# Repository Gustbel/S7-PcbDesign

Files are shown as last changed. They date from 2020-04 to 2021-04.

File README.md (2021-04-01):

# Diseño en ALTIUM del PCB del Summits 7 - Versión RTM 1.0

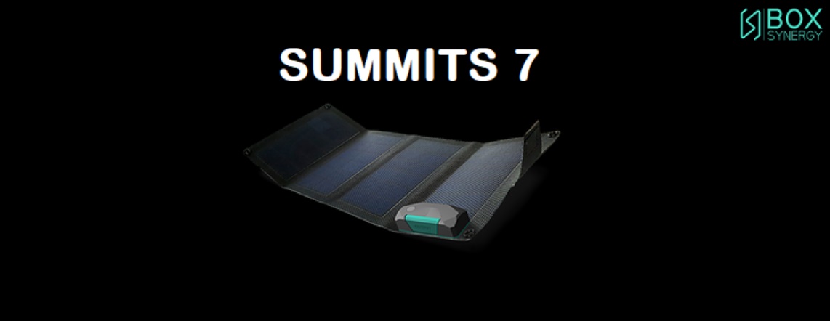
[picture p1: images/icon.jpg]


## PCB Summits 7 - Versión RTM 1.0

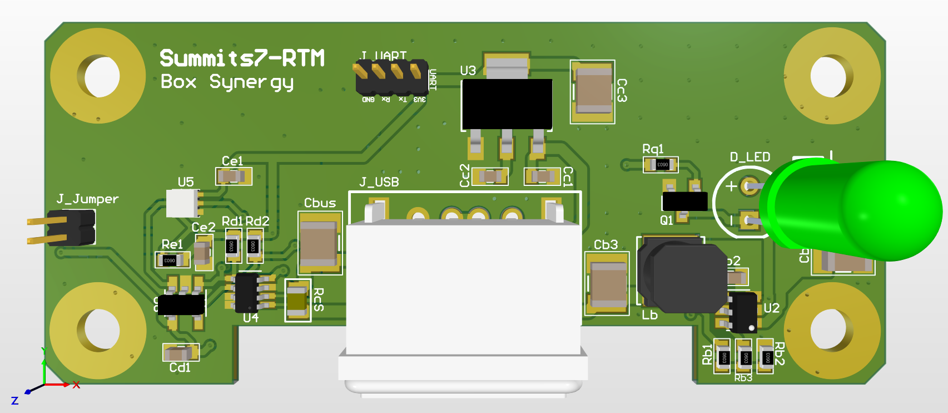
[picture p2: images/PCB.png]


## ¿Para que es este repositorio? 

 - Este repositorio servirá para tener un **Control de Versiones**, **Acceso Remoto al developer** y **Permitir Acceso continuo de avances** al equipo de trabajo de *Box Synergy*.

## ¿Como funciona este repositorio?

Este repositorio tiene dos Branches (o Ramas):

* **master:** Contiene la última versión estable, es decir después de cumplir un objetivo en el diseño y se compruebe que fue estable, se hace un salvado de datos en esta rama. Para consultar avances es preferible mirar esta rama ya que es la más estable.
* **develop:** Contiene la versión que está en desarrollo, por lo tanto probablemente inestable y con errores naturales durante el proceso de desarrollo. Esta rama es la utilizada por el desarrollador y por algún colaborador que quiera mirar o ayudar en pleno desarrollo.

## ¿Como puedo consultar el proyecto?
1. Si no lo tiene, instalar cualquier versión de Altium Designer en su PC.
2. Posicionese en el **BRANCH** (o rama) que usted desee descargar. Para seleccionar el branch haga click en el menú desplegable que está debajo del título del Repositorio (mas específicamente debajo de la descripción del repositorio) y elija el Branch que usted desee.
3. Descargar este repositorio desde un botón con tres puntos **(...)** que se encuentra en la esquina superior derecha del repositorio (al lado del botón *Clone*), luego seleccione ***Download Repository***. Se descargará un archivo comprimido *.zip*.
4. Descomprima la carpeta del Repositorio en alguna carpeta conocida.
5. Abra Altium y seleccione el proyecto que acaba de descomprimir.

## Consultas
- electronic@box-synergy.com	---  Contacto Área Electrónica de Box Synergy
- gustavobelbruno@gmail.com		---  Contacto Gustavo Belbruno - Summits 7 Beta Project Main Designer

																Repository created 05/04/2020

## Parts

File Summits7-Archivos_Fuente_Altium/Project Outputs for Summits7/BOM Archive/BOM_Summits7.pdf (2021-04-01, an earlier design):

## BOM_Summits7_RTM

Component List / BOM Archive | Company: | Box Synergy

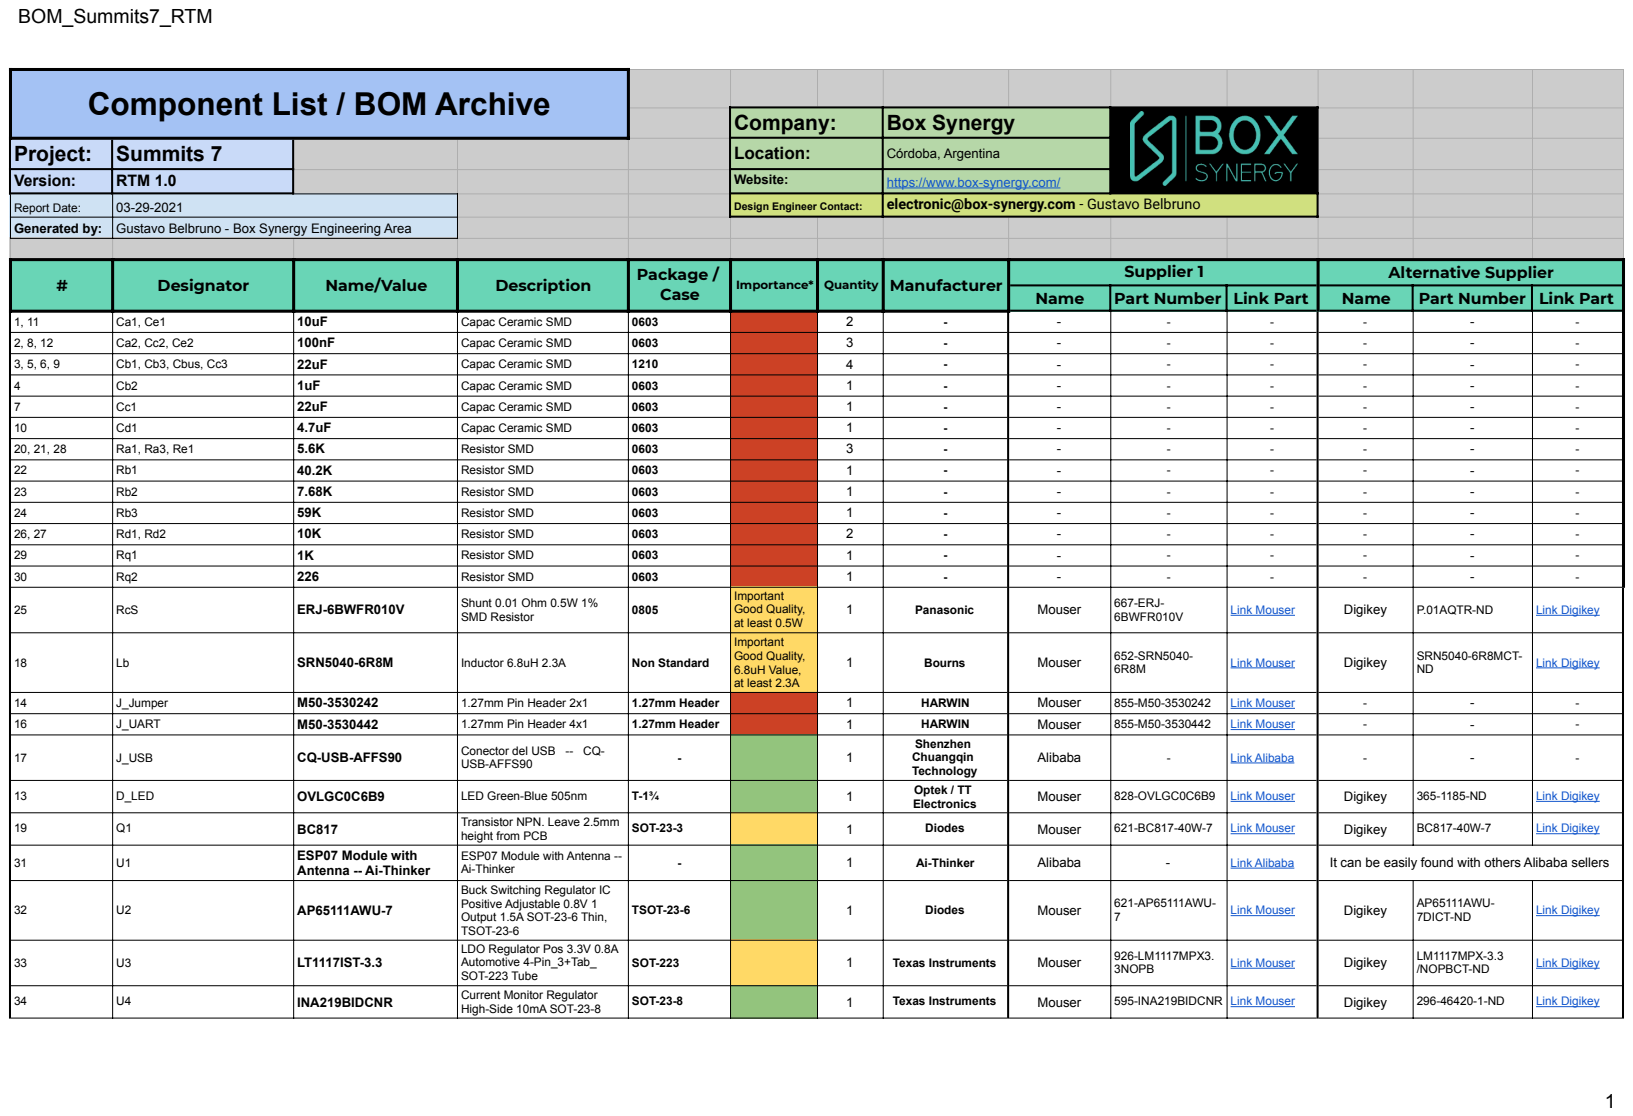
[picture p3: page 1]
Report Date:; Design Engineer Contact:; electronic@box-synergy.com - Gustavo Belbruno; Generated by:; Gustavo Belbruno - Box Synergy Engineering Area

Project: | Summits 7 | Location: | Córdoba, Argentina

Version: | RTM 1.0 | Website: | https://www.box-synergy.com/

# | Designator | Name/Value | Description | Package / Case | Importance* | Quantity | Manufacturer | Supplier 1 | Alternative Supplier

Name | Part Number | Link Part | Name | Part Number | Link Part

1, 11 | Ca1, Ce1 | 10uF | Capac Ceramic SMD | 0603 | | 2 | - | - | - | - | - | - | -

2, 8, 12 | Ca2, Cc2, Ce2 | 100nF | Capac Ceramic SMD | 0603 | | 3 | - | - | - | - | - | - | -

3, 5, 6, 9 | Cb1, Cb3, Cbus, Cc3 | 22uF | Capac Ceramic SMD | 1210 | | 4 | - | - | - | - | - | - | -

4 | Cb2 | 1uF | Capac Ceramic SMD | 0603 | | 1 | - | - | - | - | - | - | -

7 | Cc1 | 22uF | Capac Ceramic SMD | 0603 | | 1 | - | - | - | - | - | - | -

10 | Cd1 | 4.7uF | Capac Ceramic SMD | 0603 | | 1 | - | - | - | - | - | - | -

20, 21, 28 | Ra1, Ra3, Re1 | 5.6K | Resistor SMD | 0603 | | 3 | - | - | - | - | - | - | -

22 | Rb1 | 40.2K | Resistor SMD | 0603 | | 1 | - | - | - | - | - | - | -

23 | Rb2 | 7.68K | Resistor SMD | 0603 | | 1 | - | - | - | - | - | - | -

24 | Rb3 | 59K | Resistor SMD | 0603 | | 1 | - | - | - | - | - | - | -

26, 27 | Rd1, Rd2 | 10K | Resistor SMD | 0603 | | 2 | - | - | - | - | - | - | -

29 | Rq1 | 1K | Resistor SMD | 0603 | | 1 | - | - | - | - | - | - | -

30 | Rq2 | 226 | Resistor SMD | 0603 | | 1 | - | - | - | - | - | - | -
25 | RcS | ERJ-6BWFR010V | Shunt 0.01 Ohm 0.5W 1% SMD Resistor | 0805 | Important Good Quality, at least 0.5W | 1 | Panasonic | Mouser | 667-ERJ-6BWFR010V | Link Mouser (https://www.mouser.com/ProductDetail/Panasonic/ERJ-6BWFR010V) | Digikey | P.01AQTR-ND | Link Digikey (https://www.digikey.com/product-detail/en/panasonic-electronic-components/ERJ-6BWFR010V/P-01AQTR-ND/1466354)

18 | Lb | SRN5040-6R8M | Inductor 6.8uH 2.3A | Non Standard | Important Good Quality, 6.8uH Value, at least 2.3A | 1 | Bourns | Mouser | 652-SRN5040-6R8M | Link Mouser (https://www.mouser.com/ProductDetail/Bourns/SRN5040-6R8M) | Digikey | SRN5040-6R8MCT-ND | Link Digikey (https://www.digikey.co.uk/product-detail/en/bourns-inc/SRN5040-6R8M/SRN5040-6R8MCT-ND/4867788)

14 | J_Jumper | M50-3530242 | 1.27mm Pin Header 2x1 | 1.27mm Header | | 1 | HARWIN | Mouser | 855-M50-3530242 | Link Mouser (https://www.mouser.com/ProductDetail/Harwin/M50-3530242?qs=%252BdQmOuGyFcFfqfwYQe%2FxZw%3D%3D) | - | - | -

16 | J_UART | M50-3530442 | 1.27mm Pin Header 4x1 | 1.27mm Header | | 1 | HARWIN | Mouser | 855-M50-3530442 | Link Mouser (https://www.mouser.com/ProductDetail/Harwin/M50-3530242?qs=%252BdQmOuGyFcFfqfwYQe%2FxZw%3D%3D) | - | - | -
17 | J_USB | CQ-USB-AFFS90 | Conector del USB -- CQ-USB-AFFS90 | - | | 1 | Shenzhen Chuangqin Technology | Alibaba | - | Link Alibaba (https://www.alibaba.com/product-detail/4-Pin-Waterproof-IPX8-USB-A_62420880597.html) | - | - | -

13 | D_LED | OVLGC0C6B9 | LED Green-Blue 505nm | T-1¾ | | 1 | Optek / TT Electronics | Mouser | 828-OVLGC0C6B9 | Link Mouser (https://www.mouser.com/ProductDetail/Optek-TT-Electronics/OVLGC0C6B9?qs=3Y%252Bkm9Tbno7Cu33sFcjmUA%3D%3D) | Digikey | 365-1185-ND | Link Digikey (https://www.digikey.co.uk/product-detail/en/tt-electronics-optek-technology/OVLGC0C6B9/365-1185-ND/827121)

19 | Q1 | BC817 | Transistor NPN. Leave 2.5mm height from PCB | SOT-23-3 | | 1 | Diodes | Mouser | 621-BC817-40W-7 | Link Mouser (https://www.mouser.com/ProductDetail/Diodes-Incorporated/BC817-40W-7/) | Digikey | BC817-40W-7 | Link Digikey (https://www.digikey.com/en/products/detail/BC817-40W-7/BC817-40WDICT-ND/816560)

31 | U1 | ESP07 Module with Antenna -- Ai-Thinker | ESP07 Module with Antenna --Ai-Thinker | - | | 1 | Ai-Thinker | Alibaba | - | Link Alibaba (https://www.alibaba.com/product-detail/Ai-Thinker-ESP-07-ESP8266-Wifi_62009924257.html) | It can be easily found with others Alibaba sellers

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

## BOM_Summits7_RTM

2

35 | U5 | VEML6030 | Optical Ambiental Light Sensor I2C with Interrupt | Surface-mount (not detailed in datasheet) | 1 | Vishay | Mouser | 78-VEML6030 | Link Mouser (https://www.mouser.com/ProductDetail/Vishay-Semiconductors/VEML6030/?qs=oeTp6q%252Bm7GMZCCnCKRrv4g%3D%3D) | - | - | -
36 | U6 | 24CW1280T-I/OT | EEPROM 128K I2C | SOT-23-5 | 1 | Microchip | Mouser | 579-24CW1280T-I/OT | Link Mouser (https://www.mouser.com/ProductDetail/Microchip-Technology/24CW1280T-I-OT?qs=qSfuJ%252Bfl%2Fd6lIWZGGRvkYA==) | Digikey | 24CW1280T-I/OTCT-ND | Link Digikey (https://www.digikey.com/product-detail/en/microchip-technology/24CW1280T-I-OT/24CW1280T-I-OTCT-ND/9607061)
15 | J_Solar | Connx2_Panel | No component
*Importance: Refers to the importance of using the designated component and not a default replacement | This is a critical device and was specially calculated, it should not be exchanged for any device. In case of not obtaining this device, please contact the design engineer.
| If possible, use the supplied device. In case there is difficulty in obtaining it, you can use another one with similar characteristics, but as long as the device has a complete datasheet where its parameters can be consulted.
| This is a regular device and you can choose the device that suits you.

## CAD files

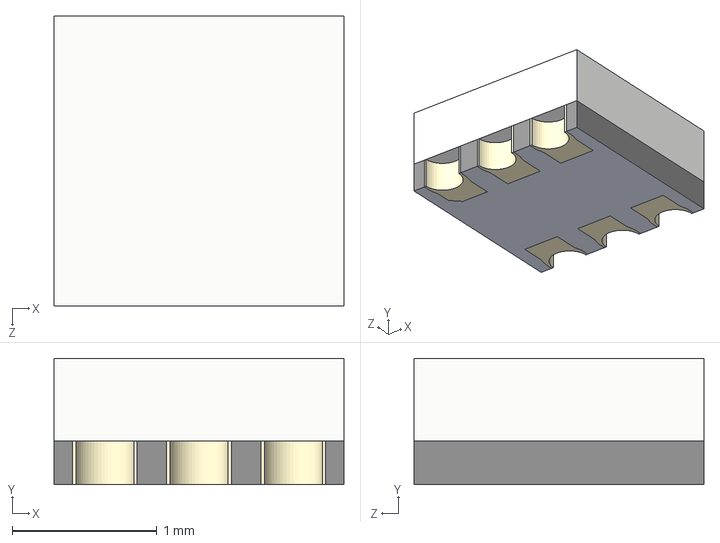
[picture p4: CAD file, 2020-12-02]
Summits7-Archivos_Fuente_Altium/LibraryUsed/Originales/STEP_Models/DFN-6-1_2.step
2.00 x 0.87 x 2.00 mm

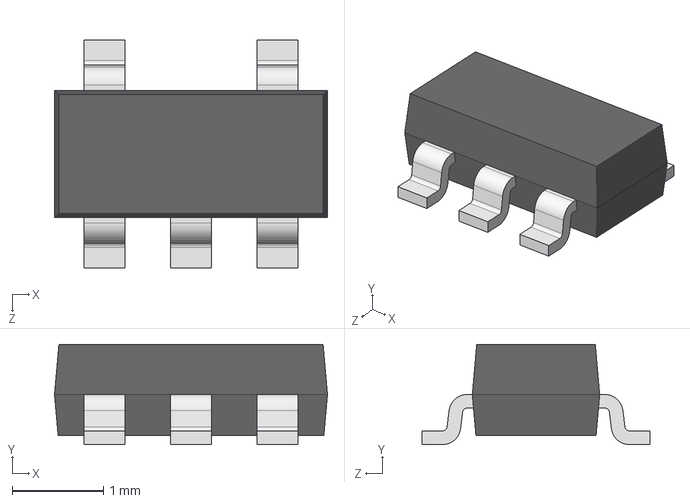
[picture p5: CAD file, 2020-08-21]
Summits7-Archivos_Fuente_Altium/LibraryUsed/Originales/STEP_Models/SOT-23-5-EEPROM.step
3.00 x 1.10 x 2.50 mm

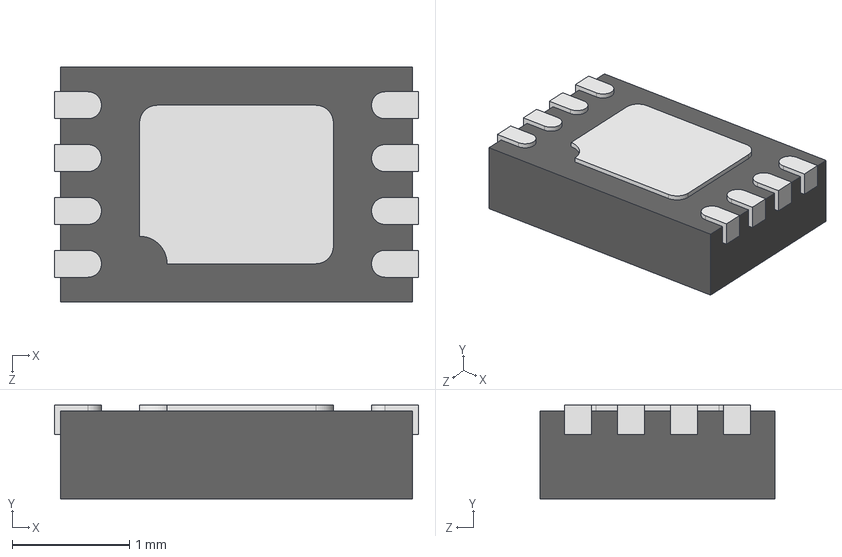
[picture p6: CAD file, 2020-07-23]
Summits7-Archivos_Fuente_Altium/LibraryUsed/Originales/STEP_Models/DFN8.step
3.10 x 0.8 x 2.00 mm

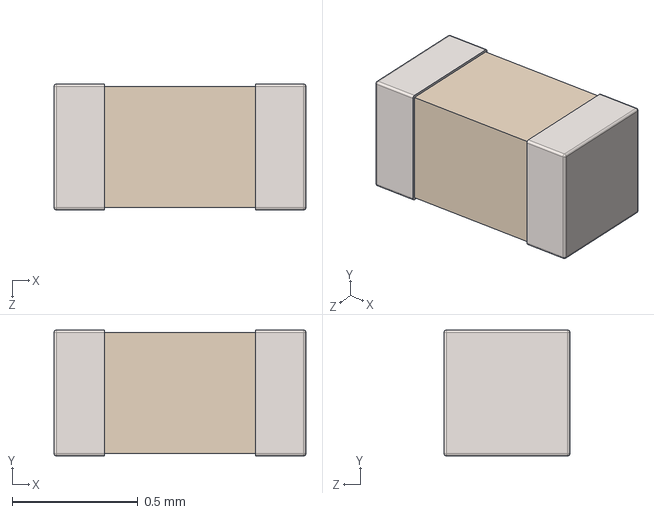
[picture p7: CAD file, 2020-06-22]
Summits7-Archivos_Fuente_Altium/LibraryUsed/Originales/STEP_Models/Cap0402.step
1.00 x 0.5 x 0.5 mm

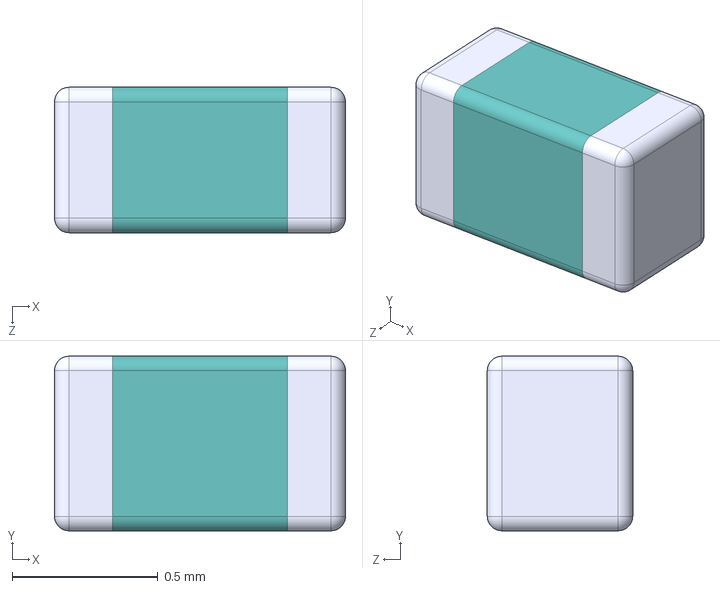
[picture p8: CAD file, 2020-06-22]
Summits7-Archivos_Fuente_Altium/LibraryUsed/Originales/STEP_Models/Ind0402.step
1.00 x 0.6 x 0.5 mm

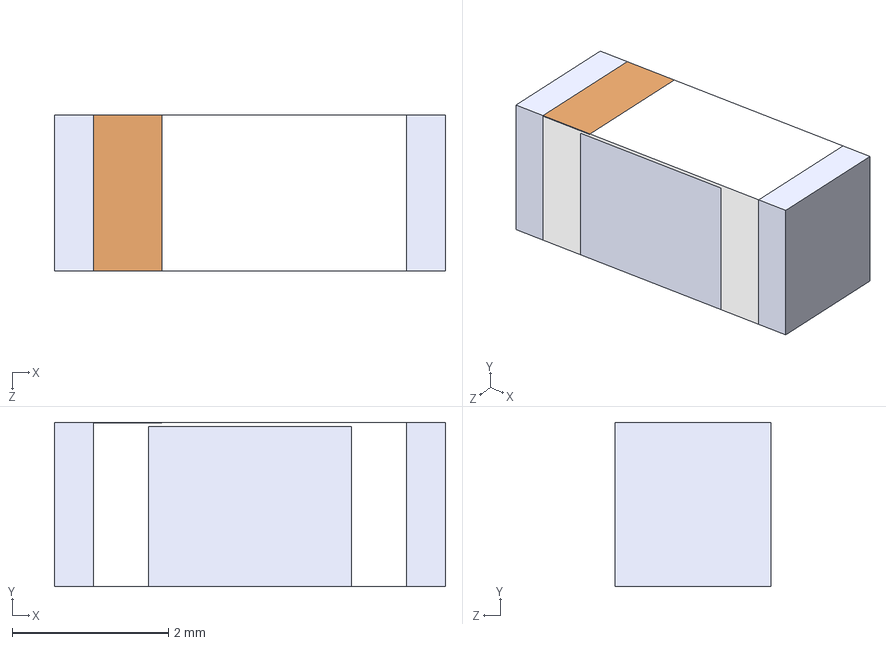
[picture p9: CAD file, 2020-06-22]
Summits7-Archivos_Fuente_Altium/LibraryUsed/Originales/STEP_Models/AntennaCeramic--2450AT42B100E.STEP
5.00 x 2.10 x 2.00 mm

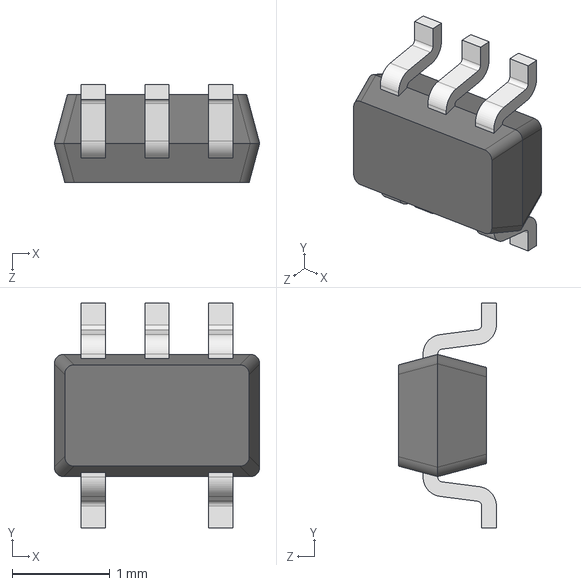
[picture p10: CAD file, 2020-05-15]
Summits7-Archivos_Fuente_Altium/LibraryUsed/Originales/STEP_Models/OPAMP-SC70-5.step
2.10 x 2.30 x 1.00 mm

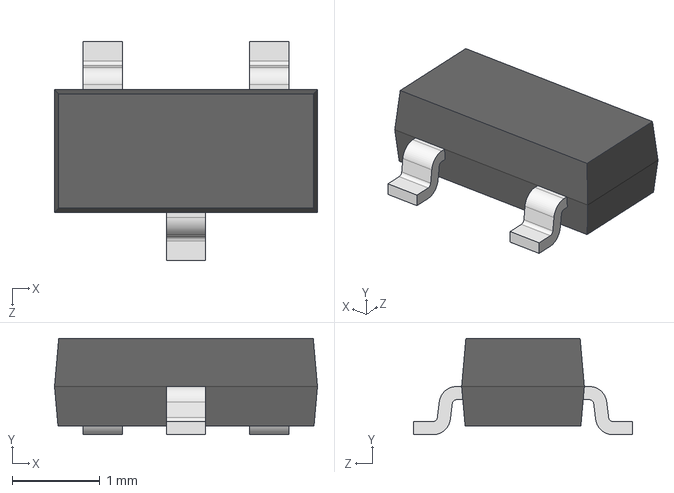
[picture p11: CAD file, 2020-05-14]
Summits7-Archivos_Fuente_Altium/LibraryUsed/Originales/STEP_Models/SOT-23_TransistorNPN.step
3.00 x 1.10 x 2.50 mm

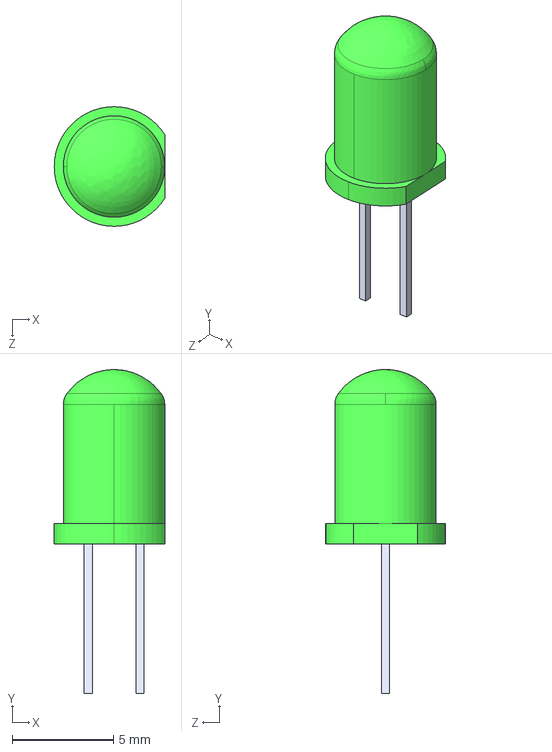
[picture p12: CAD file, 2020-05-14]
Summits7-Archivos_Fuente_Altium/LibraryUsed/Originales/STEP_Models/LED-GREEN-5mm.step
5.45 x 16.0 x 5.90 mm

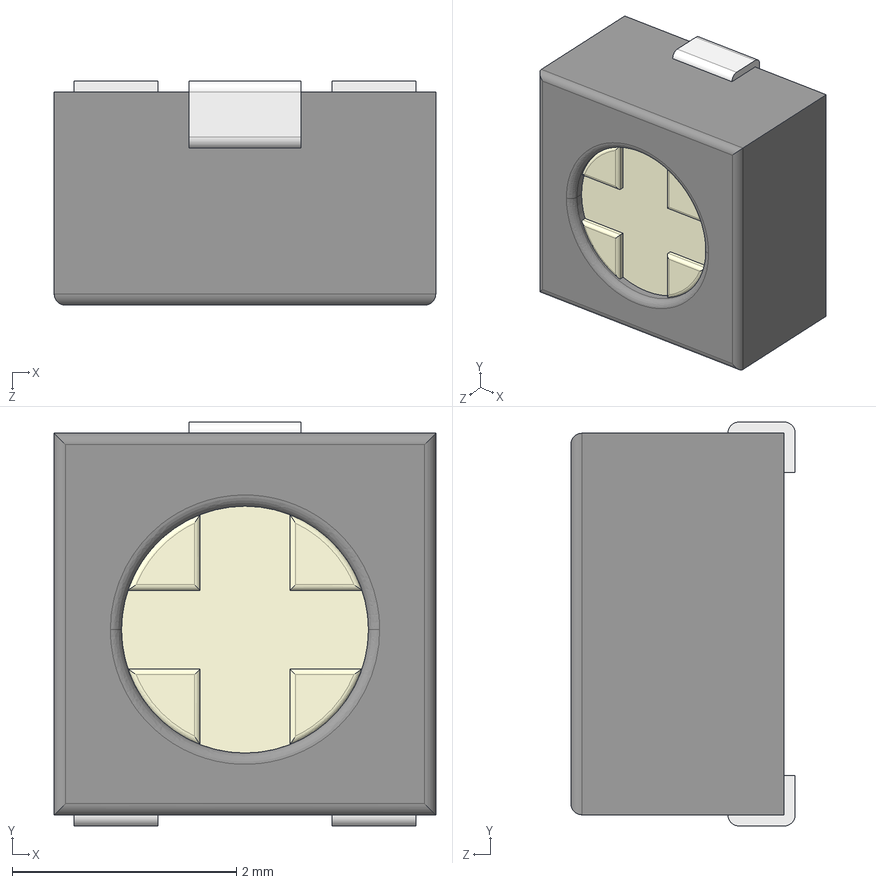
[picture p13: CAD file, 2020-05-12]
Summits7-Archivos_Fuente_Altium/LibraryUsed/Originales/STEP_Models/TRIMMER_PVG3A.STEP
3.40 x 3.60 x 2.00 mm
ACIS Solid_3223
ACIS Solid_3378
ACIS Solid_3314
ACIS Solid_3586
ACIS Solid_3259

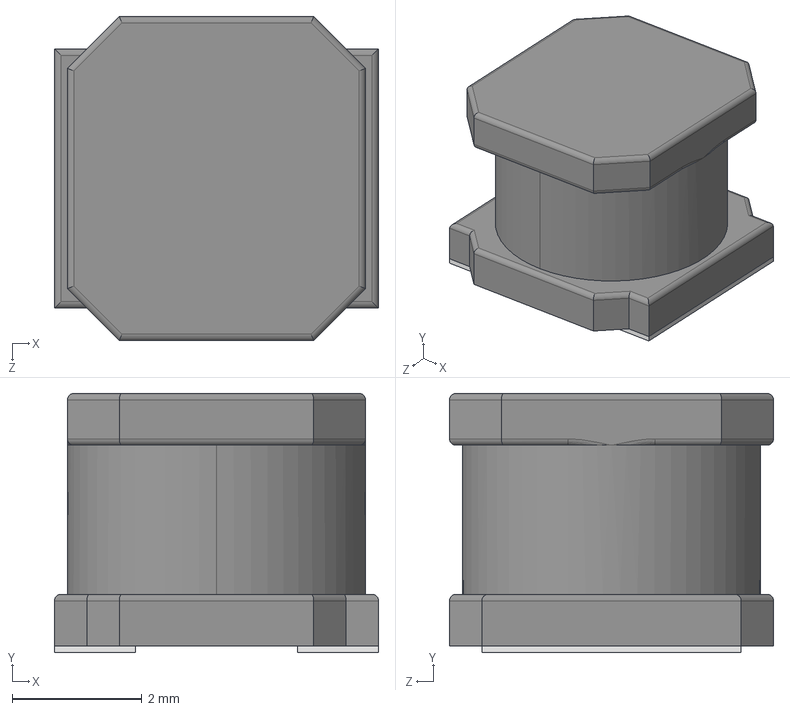
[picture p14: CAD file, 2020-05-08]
Summits7-Archivos_Fuente_Altium/LibraryUsed/Originales/STEP_Models/Inductor_Buck_SRN5040.step
5.00 x 4.00 x 5.00 mm

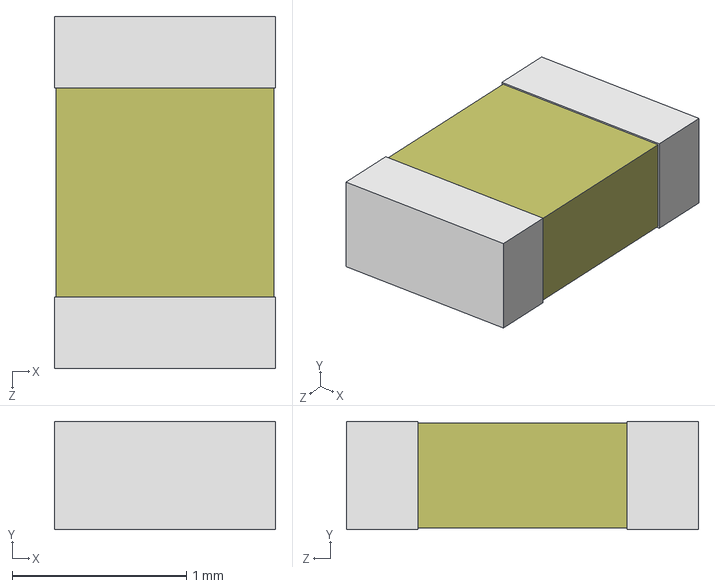
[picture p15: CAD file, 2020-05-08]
Summits7-Archivos_Fuente_Altium/LibraryUsed/Originales/STEP_Models/Shunt_0805.step
1.27 x 0.62 x 2.02 mm

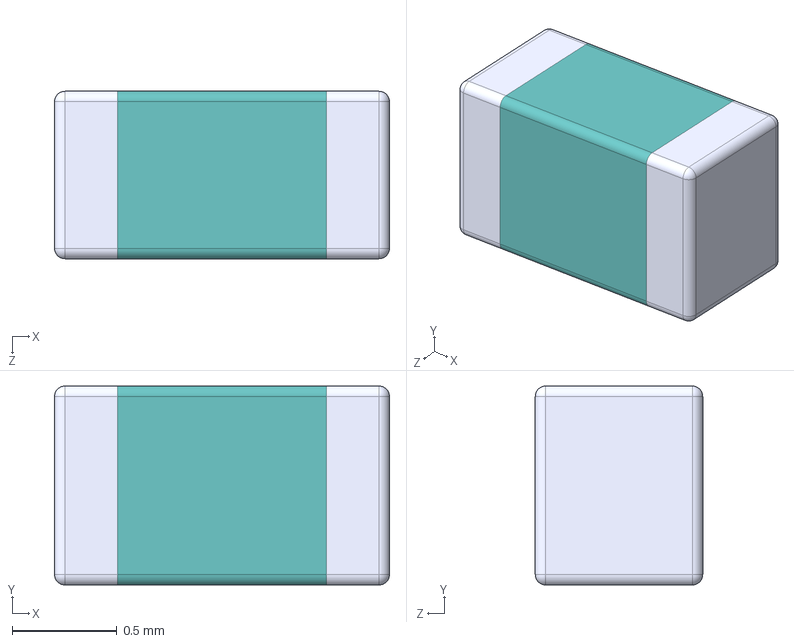
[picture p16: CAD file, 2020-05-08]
Summits7-Archivos_Fuente_Altium/LibraryUsed/Originales/STEP_Models/Ind0603.step
1.60 x 0.95 x 0.8 mm

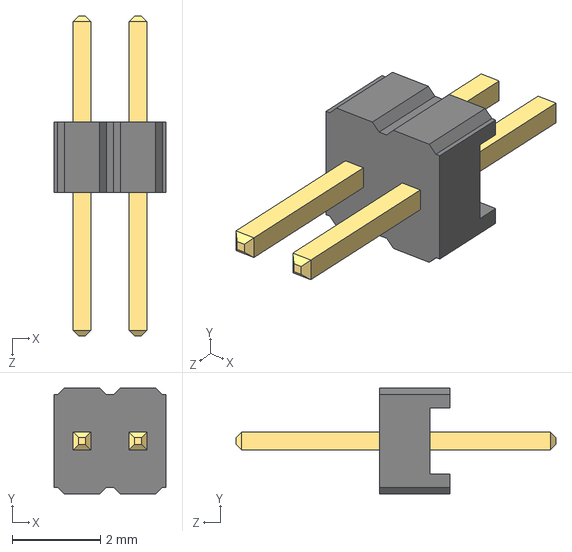
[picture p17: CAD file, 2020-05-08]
Summits7-Archivos_Fuente_Altium/LibraryUsed/Originales/STEP_Models/Header_127mm_Pitch2-1_usar2.step
2.54 x 2.40 x 7.25 mm

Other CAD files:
Summits7-Archivos_Fuente_Altium/LibraryUsed/Originales/STEP_Models/INA219_SOT23.STEP
Summits7-Archivos_Fuente_Altium/LibraryUsed/Originales/STEP_Models/Header_254mm_Pitch4-1.step
Summits7-Archivos_Fuente_Altium/LibraryUsed/Originales/STEP_Models/Header_254mm_Pitch2-1.step
Summits7-Archivos_Fuente_Altium/LibraryUsed/Originales/STEP_Models/PT2512FK-070R1L.STEP
Summits7-Archivos_Fuente_Altium/LibraryUsed/Originales/STEP_Models/ABM8-26MHz.STEP
Summits7-Archivos_Fuente_Altium/LibraryUsed/Originales/STEP_Models/AP65111A-SOT23-6.step
Summits7-Archivos_Fuente_Altium/LibraryUsed/Originales/STEP_Models/Cap0603.step
Summits7-Archivos_Fuente_Altium/LibraryUsed/Originales/STEP_Models/Cap1210.step
Summits7-Archivos_Fuente_Altium/LibraryUsed/Originales/STEP_Models/ESP8266EX.STEP
Summits7-Archivos_Fuente_Altium/LibraryUsed/Originales/STEP_Models/Fotodiodo_VBPW34S.step
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

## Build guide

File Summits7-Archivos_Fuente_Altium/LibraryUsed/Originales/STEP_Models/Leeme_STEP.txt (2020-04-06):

Si estaban disponibles los modelos fueron descargados de: https://www.snapeda.com/
En caso de no encontrarlos ahí se sacaron de: https://www.3dcontentcentral.com/

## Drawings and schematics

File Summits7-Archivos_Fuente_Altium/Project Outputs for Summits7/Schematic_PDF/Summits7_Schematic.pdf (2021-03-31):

# USB out

# Ai-Thinker -- ESP8266 Module

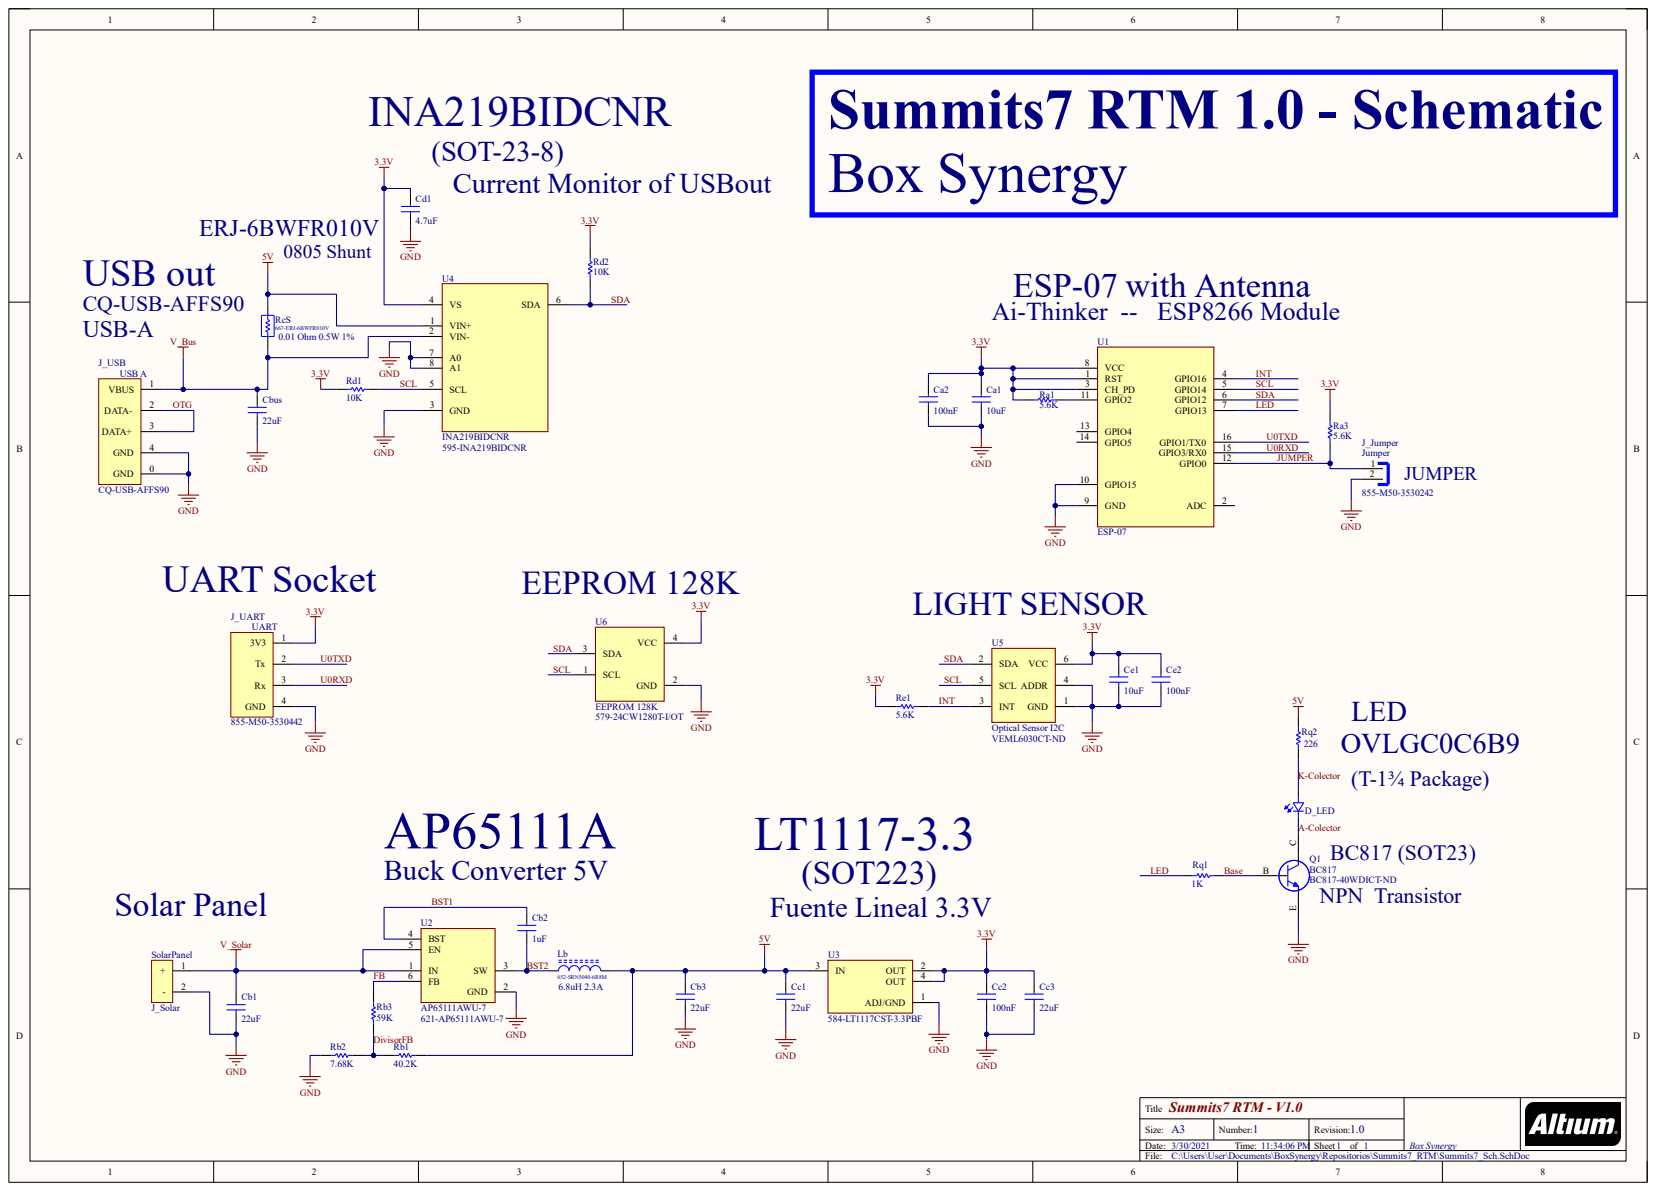
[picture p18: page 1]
Box Synergy; Size:; Number:; Date: File:; Revision:; Time:; Sheet; V_Solar; V_Bus; GND; SolarPanel; J_Solar; 584-LT1117CST-3.3PBF; OUT; ADJ/GND; UART; J_UART; U0TXD; U0RXD; SDA; SCL; 595-INA219BIDCNR; VIN+ 1 VIN- 2; SCL 5; GND 3; INA219BIDCNR; 667-ERJ-6BWFR010V; RcS; 0.01 Ohm 0.5W 1%; 621-AP65111AWU-7; BST 4 EN 5; AP65111AWU-7; 652-SRN5040-6R8M; D_LED; Cbus; DivisorFB; BST1; BST2; OTG; Jumper; J_Jumper; JUMPER; Solar Panel; Buck Converter 5V; Fuente Lineal 3.3V; OVLGC0C6B9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

ESP-07 with Antenna

Summits7 RTM - V1.0
Title
C:\Users\User\Documents\BoxSynergy\Repositorios\Summits7_RTM\Summits7_Sch.SchDoc

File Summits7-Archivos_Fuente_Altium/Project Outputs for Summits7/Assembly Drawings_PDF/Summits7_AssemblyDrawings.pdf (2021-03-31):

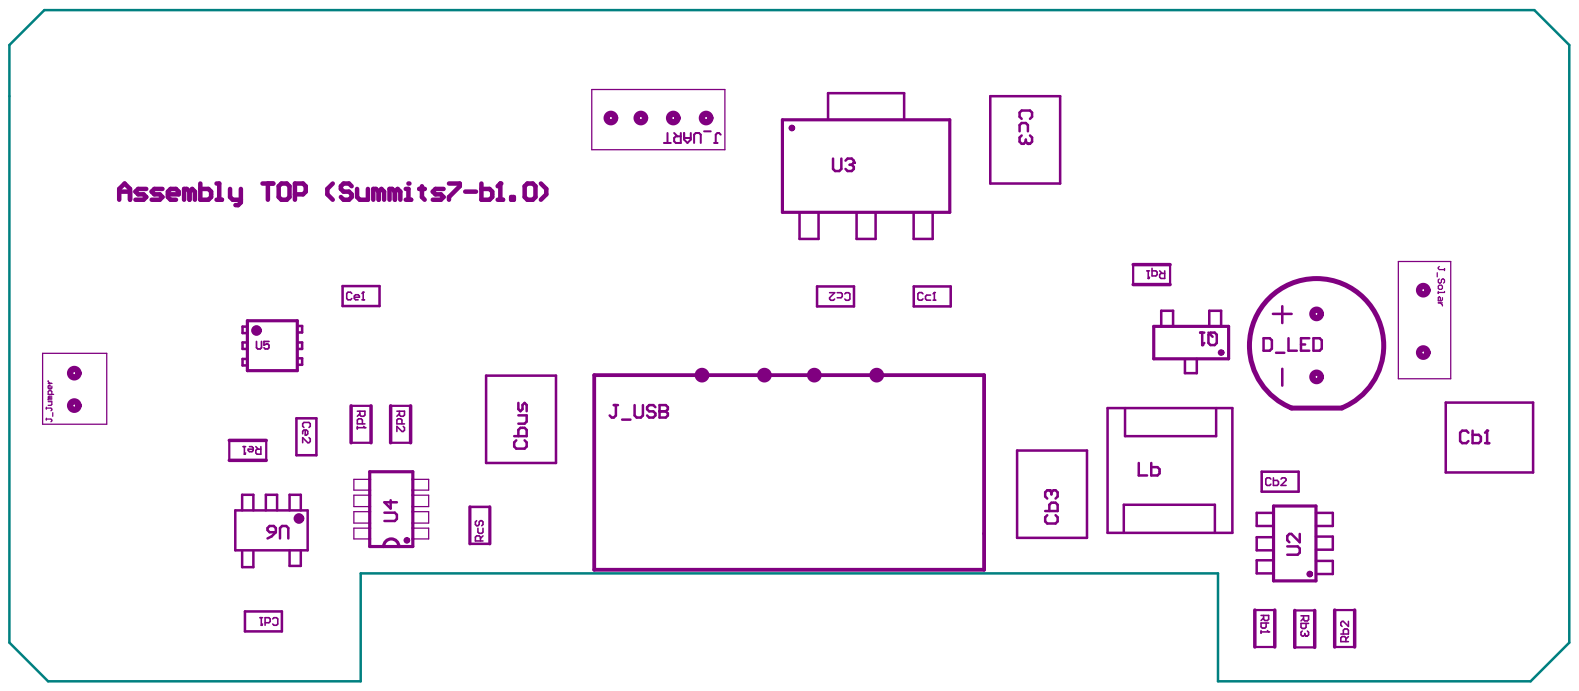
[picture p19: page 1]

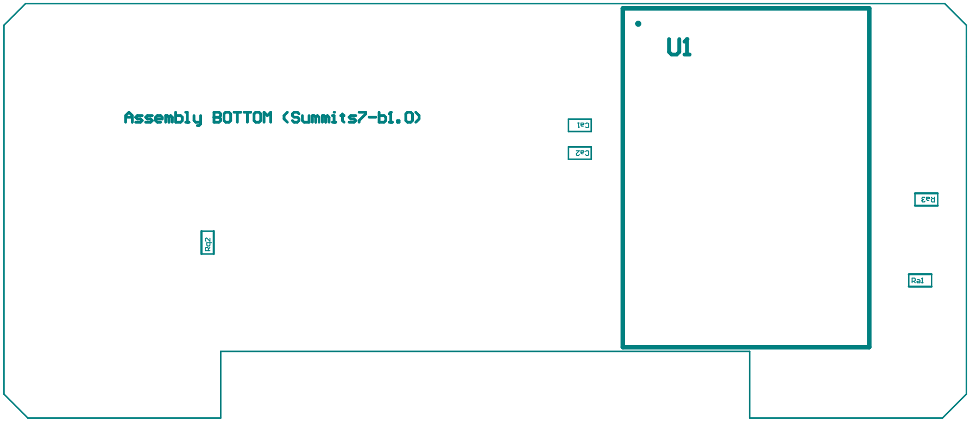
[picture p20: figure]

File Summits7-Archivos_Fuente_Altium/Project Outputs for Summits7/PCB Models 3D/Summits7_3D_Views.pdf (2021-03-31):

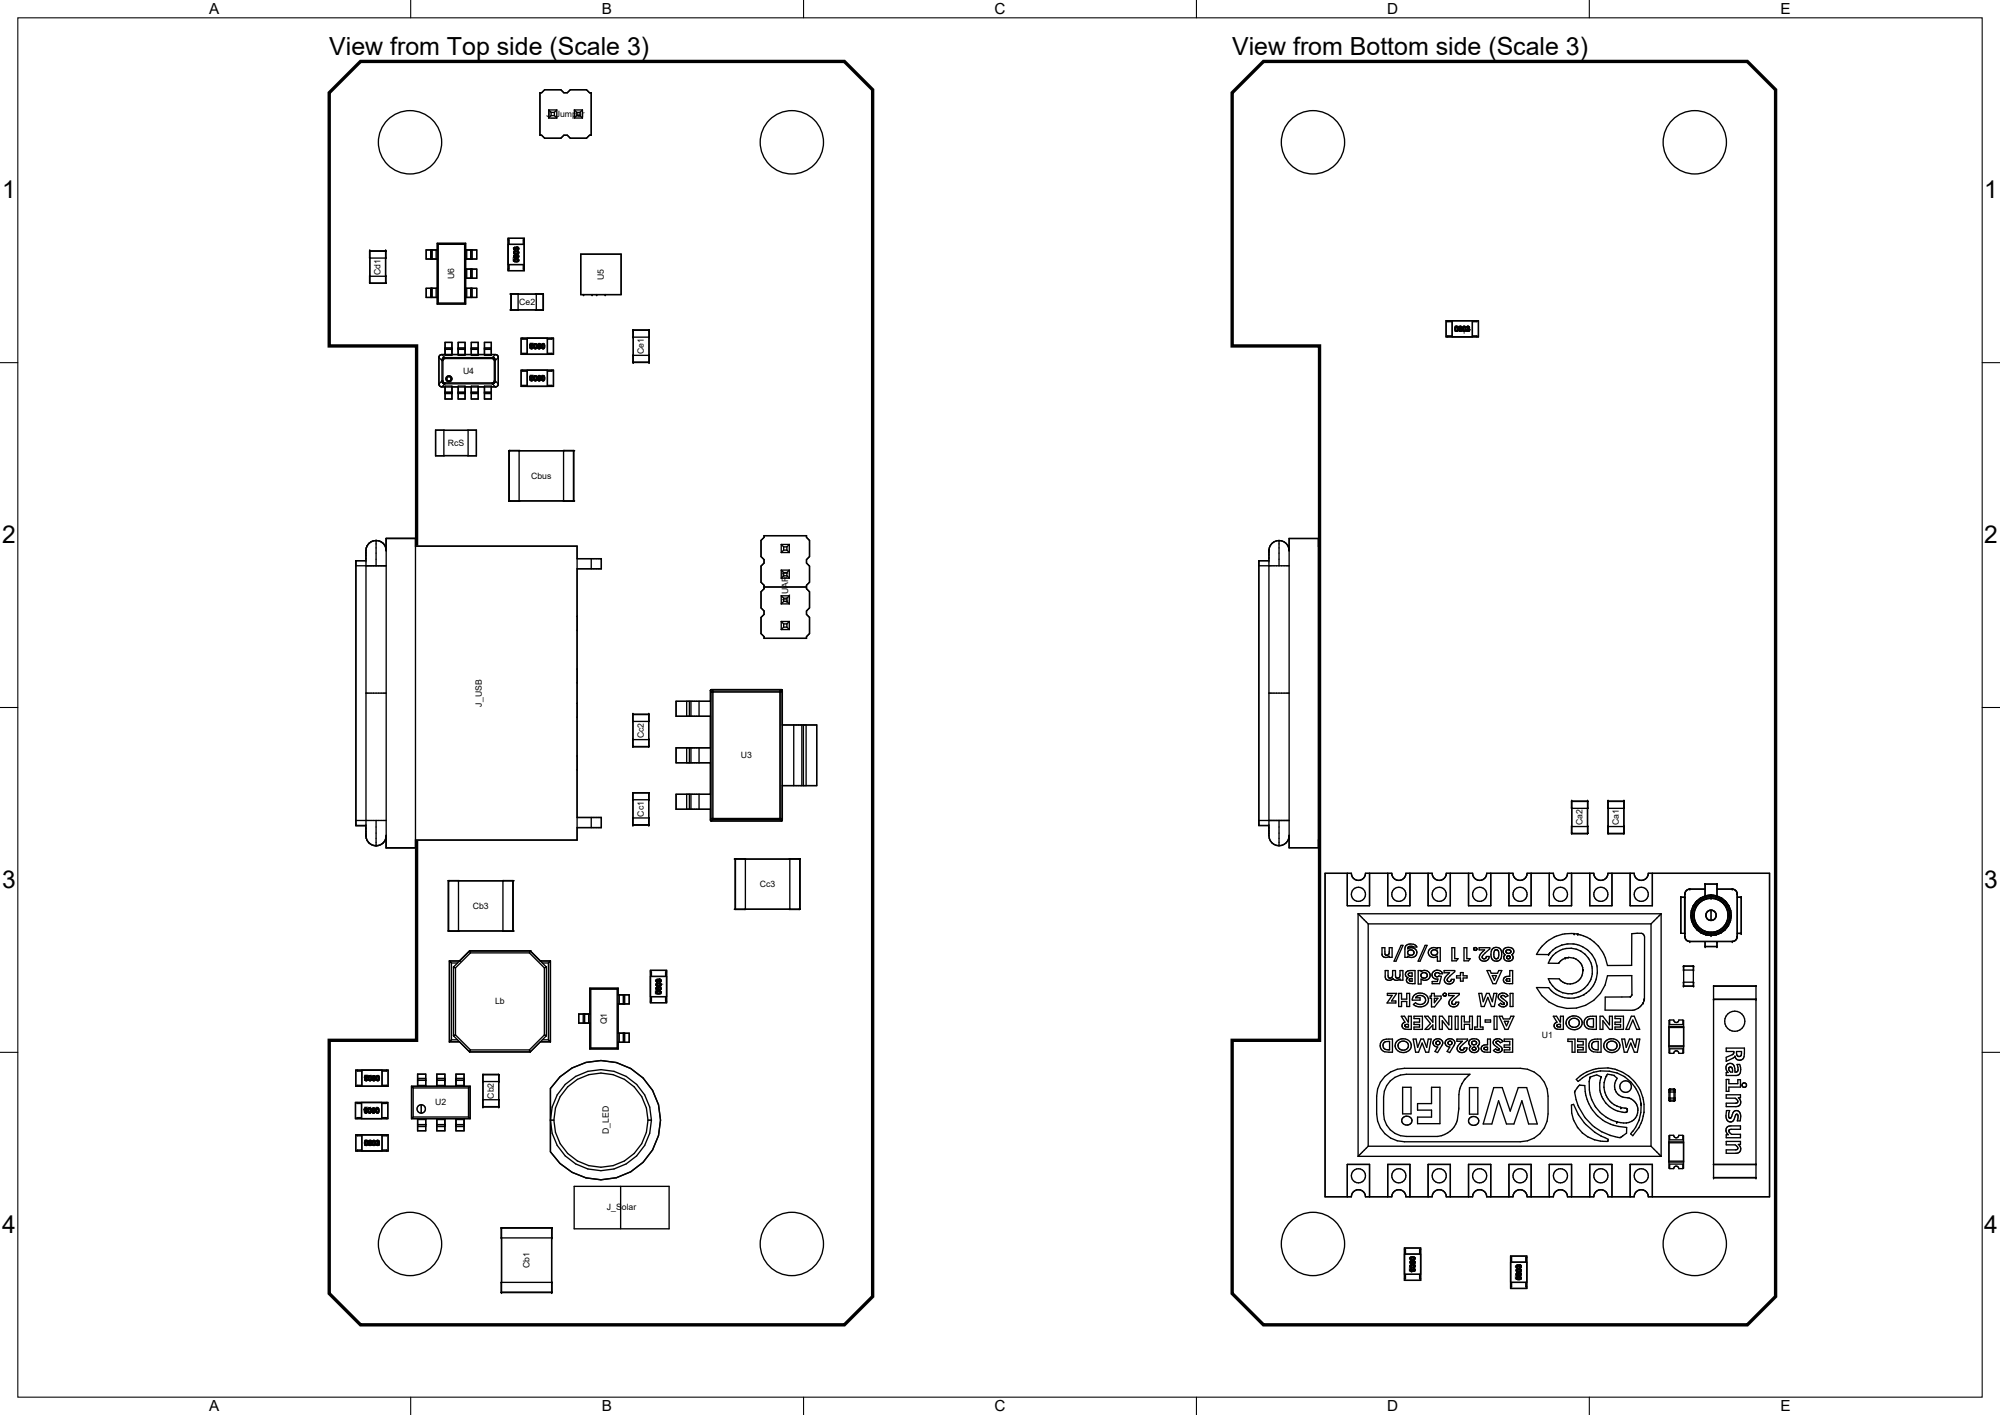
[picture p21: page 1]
4 J_USB; J_Solar; RcS; Cb1 Cbus; J_UART; J_Jumper; J_USB; D_LED

View from Top side (Scale 3)

View from Bottom side (Scale 3)

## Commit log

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2020-04-10 - Cargado Conector UART y USB A - Correcciones Varias en los layers de los footprints
    [Header_254mm_Pitch4-1.step, Summits7Beta_LIB_Conectores_PCB.PcbLib, Summits7Beta_LIB_Conectores_Sch.SchLib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]
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2020-04-16 - Circuito INA219 listo. - Corrección en Circuito del Fotodiodo (El Fotodiodo estaba colocado al revés). - Corrección en Circuito del Fotodiodo (Se agregó un divisor resistivoa la salida del operacio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
    [Summits7Beta_LIB_Integrados_Sch.SchLib, Summits7Beta_Sch.SchDoc]
2020-05-08 Vuelta al Altium - Cambiado INA219B por el SOT23 - Agregado Nueva Fuente Buck AP65111A - Borrado del Schematic el INA219 viejo y el Buck Viejo (todavía no se reemplazó por los nuevos)
    [AP65111A-SOT23-6.step, INA219_SOIC8-150.STEP, INA219_SOT23.STEP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]
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2020-05-08 - Actualizado el Header del UART programador por uno más pequeño. - Se borró el Bottom de la antena wifi que no tenía sentido
    [Header_127mm_Pitch2-1_usar2.step, Summits7Beta_LIB_Conectores_PCB.PcbLib, Summits7Beta_LIB_Conectores_Sch.SchLib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]
2020-05-08 - Corregido medidas de footprint de pasivos. - Corregido inductor 0603 que estaba muy mal el tamaño - Cargado Nuevo Shunt. - Se elimino el Shunt anterior tanto de la libreria como del schematic
    [Ind0603.step, Shunt_0805.step, Summits7Beta_LIB_Integrados_PCB.PcbLib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]
2020-05-08 - Cargado Nuevo Inductor. Se corrigió sobre el mismo inductor que estaba antes.
    [Ind_2525.step, Inductor_Buck_SRN5040.step, Summits7Beta_LIB_Pasivos_PCB.PcbLib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]
2020-05-12 - Agregado Trimmer para controlar la ganancia del Operacional. - Corregido Schematic de la antena que todavia no se habia borrado la pata del GND - Corregido el Schematic (ya estaría completo)
    [Summits7Beta_LIB_Otros_Sch.SchLib, Summits7Beta_LIB_Pasivos_PCB.PcbLib, Summits7Beta_LIB_Pasivos_Sch.SchLib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]
2020-05-14 Actualizaciones Varias. - Agregado Circuito del Led - Corregido Amplificador con valores corregidos. - Agregado resistencias pull up INA219 - Corregido valores de resistencia ESP8266
    [LED-GREEN-5mm.step, SOT-23_TransistorNPN.step, Summits7Beta_LIB_Integrados_PCB.PcbLib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]
2020-05-15 - Agregado Resistencia Pull Up a PIN 15 (jumper) del ESP8266 - Nueva antena de Wifi con Medidas calculadas
    [Summits7Beta_LIB_Otros_PCB.PcbLib, Summits7Beta_LIB_Otros_Sch.SchLib, Summits7Beta_Sch.SchDoc]
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2020-05-15 - Cargados todos los Designators Correctos en el Schematic
    [Summits7Beta_PCB.PcbDoc, Summits7Beta_Sch.SchDoc]
2020-05-15 - Corregidos Errores de Compilación, Ahora compila Perfecto
    [Summits7Beta_LIB_Conectores_Sch.SchLib, Summits7Beta_LIB_Integrados_Sch.SchLib, Summits7Beta_LIB_Otros_Sch.SchLib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]
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2020-05-28 Falta agregar Solo el plano de masa y arreglar unos detalles de las vias
    [Summits7Beta_LIB_Otros_PCB.PcbLib, Summits7Beta_PCB1.PcbDoc]
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2020-06-03 - Corregido Polarización del Fotodiodo - Modificado Trimmer del Fotodiodo a 20k - Agregada la conexión cortocircuito OTG
    [Summits7Beta_LIB_Pasivos_Sch.SchLib, Summits7Beta_PCB1.PcbDoc, Summits7Beta_Sch.SchDoc]
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2020-06-11 - Agregado resistencia PullUp al GPIO2 tanto en schematic como en PCB
    [Summits7Beta_PCB1.PcbDoc, Summits7Beta_Sch.SchDoc]
2020-06-22 Varios Cambios Importantes: - Se agregó a la librería la nueva antena de cerámica a usar (Schematic y Footprint) - Se agregó a la librería capacitor e Inductor 0402 que usaremos en la antena - Se Agr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
    [AntennaCeramic--2450AT42B100E.STEP, Cap0402.step, Ind0402.step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]
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2020-06-22 - Se colocó mas adelante el USB en la placa Summits. - Al tener mas espacio disponible se corrió de lugar algunos componentes como el capacitor a la salida del Buck y el jumper - Se ruteó toda esa pa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
    [Summits7Beta_PCB1.PcbDoc]
2020-06-22 Se agregó un nuevo Archivo de PCB porque no romperemos el que tiene la antena vieja. Por si las dudas
    [Summits7Beta.PrjPcb, Summits7Beta_PCB2.PcbDoc]
2020-06-23 - Modificado el Schematic porque borramos la antena PCB y la cambiamos por la antena cerámica. También cambiamos los pasivos del puente pi que eran 0806 por 0402. - Ruteamos la nueva antena siguiendo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
    [Summits7Beta_LIB_Otros_Sch.SchLib, Summits7Beta_LIB_Pasivos_PCB.PcbLib, Summits7Beta_PCB2.PcbDoc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]
2020-07-06 Arreglos varios. Faltan solo detalles
    [Summits7Beta.PrjPcb, Summits7Beta_LIB_Conectores_PCB.PcbLib, Summits7Beta_LIB_Otros_PCB.PcbLib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]
2020-07-06 Listo el diseño. - Arreglado los planos de masa. - Corregido valores de resistencia del Led. - Modificado el puente Pi para que esté mas cerca de la antena. - Agregada la conexión al Sleep. - Corregi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
    [Summits7Beta_LIB_Pasivos_Sch.SchLib, Summits7Beta_PCB2.PcbDoc, Summits7Beta_Sch.SchDoc]
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2020-07-08 Check 1: - Actualizados valores de capacitores del Cristal por unos acordes al datasheet - Puestos los soportes del USB a masa
    [Summits7Beta.PrjPcb, Summits7Beta_PCB2.PcbDoc, Summits7Beta_Sch.SchDoc]
2020-07-08 Check 2: - Cambio resistencia Ra3 de 500 a 499 acordes al datasheet Hardware Guideline ESP8266EX - Normalización de todos los valores de resistencia para evitar confusiones
    [Summits7Beta_PCB2.PcbDoc, Summits7Beta_Sch.SchDoc]
2020-07-09 Check 3-4: - Resistencia Ra2 cambiada de 220 a 200 - Se saco pista por debajo del Crystal rotandolo, tambien se cambio de lugar un componete que estaba en bottom en la misma altura que el crystal
    [Summits7Beta_PCB2.PcbDoc, Summits7Beta_Sch.SchDoc]
2020-07-10 Check5: - Retocado un poco el Plano de Masa, se agregaron algunas vías - Se retocó el Schematic cambiando todo al idioma inglés y detallando componentes.
    [Summits7Beta_PCB2.PcbDoc, Summits7Beta_Sch.SchDoc]
2020-07-11 Check6: - Se corrió de lugar algunos componentes debido a que desde la parte de diseño se pidió que algunos componentes de bottom estén más alejados del borde del PCB. Se puedo completar el pedido ex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
    [Summits7Beta_LIB_Conectores_PCB.PcbLib, Summits7Beta_LIB_Conectores_Sch.SchLib, Summits7Beta_LIB_Otros_PCB.PcbLib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]
2020-07-12 Check7: - Se puso a masa el A0 y A1 ya que de esta forma se define la direccion de memoria donde se alojaran los registros, aunque tambien funciona flotante, es mas seguro de esta forma.
    [Summits7Beta_PCB2.PcbDoc, Summits7Beta_Sch.SchDoc]
2020-07-14 Check 8 -Ultimo Check: - Se comprobo los pads de todos los componentes. - Se corrigieron detalles muy menores
    [Summits7Beta_LIB_Integrados_Sch.SchLib, Summits7Beta_PCB2.PcbDoc]
2020-07-15 Generacion de Outputs - Parte 1: - Generación de Archivo OUTPUT - Se generó PDF del Schematic - Se generó Archivo STEP en 3D del PCB - Se generó un PDF con los layers del PCB
    - Se agregó un nuevo layer (Borde de Linea) al proyecto ya que es útil para el PDF de los layers
    [Summits7Beta.PrjPcb, Summits7Beta_PCB.step, Summits7Beta_PCB2.PcbDoc]
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2020-07-25 - Corregido Errorcito en el circuito Fotodiodo. - Modificado un poquito el footprint del fotodiodo para que sea mas facil de ensamblar
    [Summits7Beta_LIB_Otros_PCB.PcbLib, Summits7Beta_PCB2.PcbDoc, Summits7Beta_Sch.SchDoc]
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2020-12-01 Arreglado Detalles Schematics, Actualizado PCB
    [Summits7Beta_LIB_Integrados_Sch.SchLib, Summits7Beta_Sch.SchDoc]
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2020-12-18 Corrección de Silkscreens: Corregido tamaño de los Designators. Cambiado de lugar Entrada Panel para que este mas lejos del led Modificado el pad del hole superior izquierdo que tocaba con un pad del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
    [Summits7Beta_LIB_Integrados_Sch.SchLib, Summits7Beta_LIB_Otros_PCB.PcbLib, Summits7Beta_Sch.SchDoc]
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
